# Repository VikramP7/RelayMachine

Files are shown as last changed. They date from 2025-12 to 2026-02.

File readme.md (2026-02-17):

*<div align="right"> Vikram Procter, Minh Do | Dec, 2025 </div>*

# Relay Machine - 4-bit Computer Made of Relays

## TODO
- Fix REGister LED indicator order (right most should be Q0 as its LSBs)

## Project Overview

This project implements a very simple 4-bit computer architecture 

## Systems Overview
-   ALU (computes numbers)
-   Program Memory (the program with program counter)
-   Registers (Random Access Memory)
-   Display / Routing / Clock (Displays Register Values, connections between boards)

## Components
### Relays
Using a 24V 0.15W relay [J104D2C24VDC.15S](https://www.digikey.ca/en/products/detail/cit-relay-and-switch/J104D2C24VDC-15S/12502730)

### Flyback Diodes
Using a uni-directional TVS diode [SMAJ24A](https://www.digikey.ca/en/products/detail/littelfuse-inc/SMAJ24A/762288)

### Red LED 
For important lines LED indicator [151051RS11000](https://www.digikey.ca/en/products/detail/w%C3%BCrth-elektronik/151051RS11000/4490012)

### 1.3k Resistor
Using a 1.3k resistor (2512) for current limiting LEDs [RMCF2512FT1K30](https://www.digikey.ca/en/products/detail/stackpole-electronics-inc/RMCF2512FT1K30/1758253)  

### Board to Board Connector
Board Connector 20pos 2row rectangular connector [61202021621](https://www.digikey.ca/en/products/detail/w%C3%BCrth-elektronik/61202021621/2060592)  
Cable assembly housing keyed [61202023021](https://www.digikey.ca/en/products/detail/w%C3%BCrth-elektronik/61202023021/2060600)  
Ribbon cable 20 wire 28AWG stranded [3365/20 300](https://www.digikey.ca/en/products/detail/3m/3365-20-300/1107221) or 30AWG solid [3749/20 300](https://www.digikey.ca/en/products/detail/3m/3749-20-300/22532463)

From Amazon:
General 20pos connector [here](https://www.amazon.ca/MECCANIXITY-Ribbon-2-54mm-Connector-Displays/dp/B0DQCVXGWG/ref=sr_1_1_sspa)

### Power Supply
Also avalible on amazon [here](https://www.amazon.ca/dp/B0C4YGWZQQ/ref=sspa_dk_detail_4?)

### Board Spacers 
Hex 25mm female to female M3 threaded spacer [24438](https://www.digikey.ca/en/products/detail/keystone-electronics/24438/1532170)

## Gate Implementations with Relay
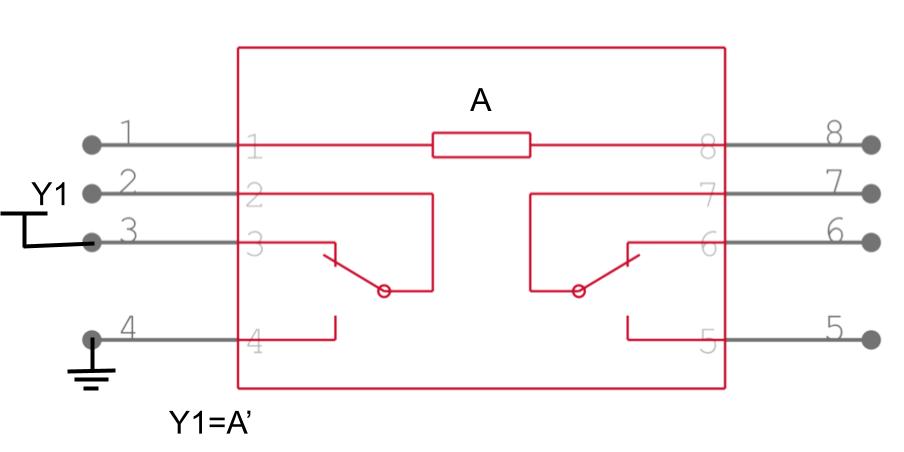
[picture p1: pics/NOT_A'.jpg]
NOT Gate

*NOT Gate Y=A'*

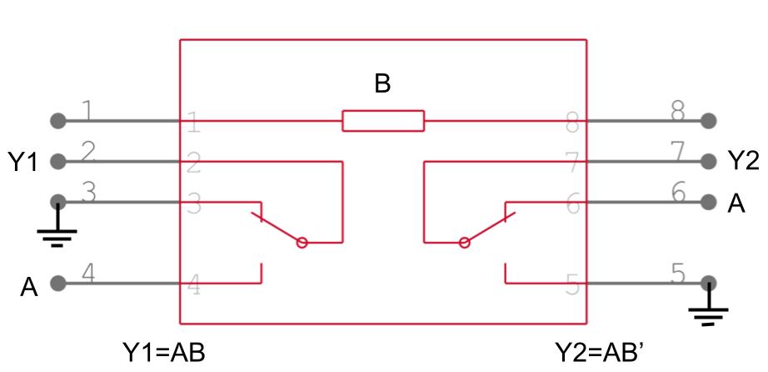
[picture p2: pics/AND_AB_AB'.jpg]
AND Gate

*AND Gate Y1=AB and Y2=AB'*

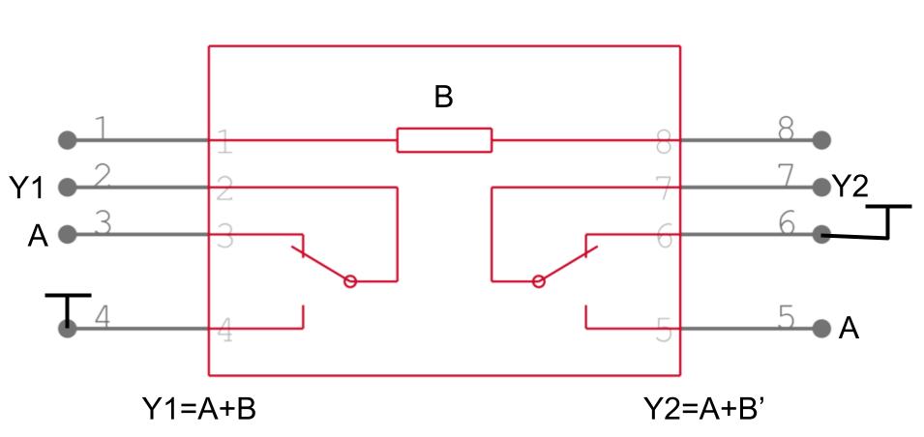
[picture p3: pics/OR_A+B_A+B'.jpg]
OR Gate

*OR Gate Y1=A+B and Y2=A+B'*

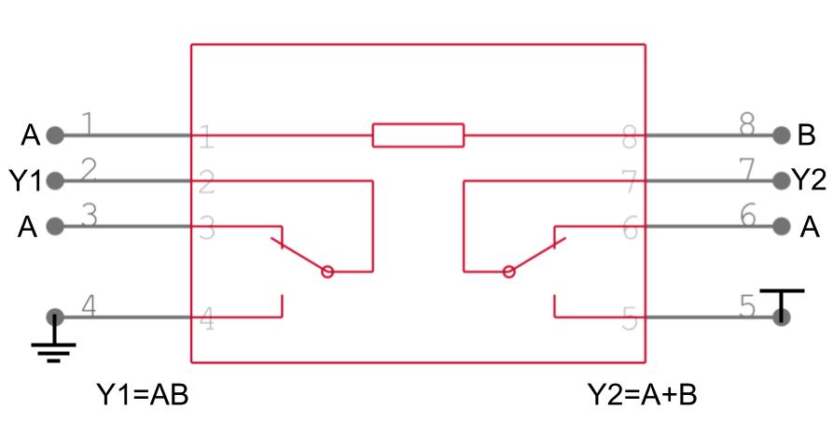
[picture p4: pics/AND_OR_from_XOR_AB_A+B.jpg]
Alternative AND OR Gate Structure

*AND or OR Gate from XOR inductor Y1=AB and Y2=A+B*

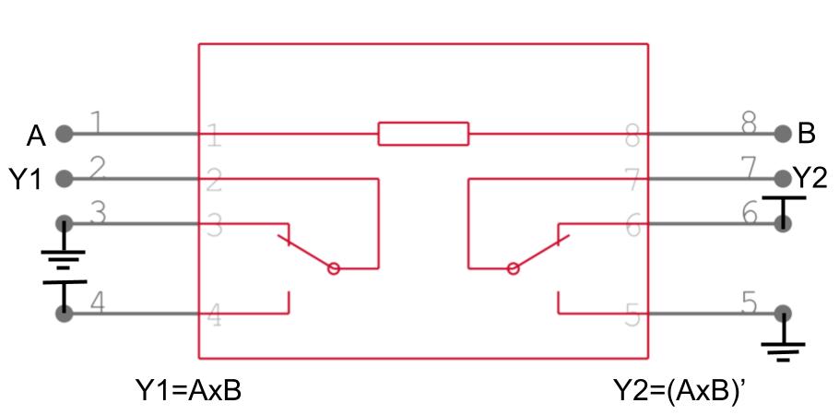
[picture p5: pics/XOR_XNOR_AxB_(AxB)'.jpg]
XOR Gate

*XOR and XNOR Gate Y1=AxB and Y2=(AxB)'*

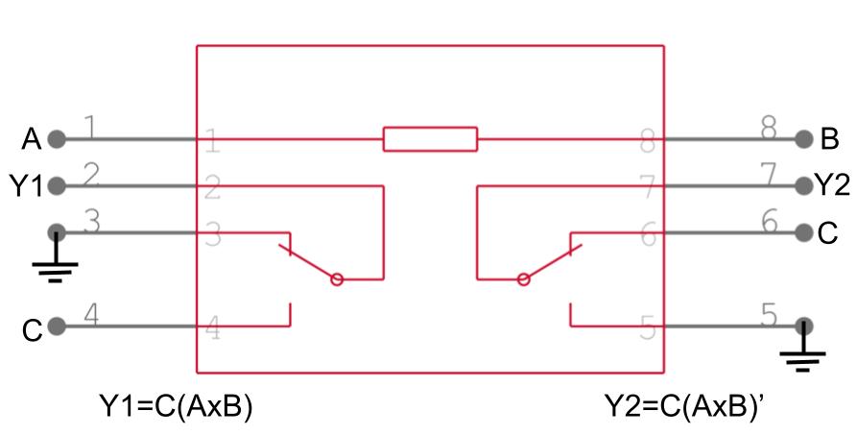
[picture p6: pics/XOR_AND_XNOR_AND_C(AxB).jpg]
XOR AND Gate

*XOR AND and XNOR AND Gate Y1=C(AxB) and Y2=C(AxB)'*

## OP-Codes
### ALU Operations:
- ADD  (addition)
- SUB  (subtraction)
- AND  (bitwise AND)
- OR   (bitwise OR)
- XOR  (bitwise exclusive OR)
- LS   (Logic shift both ways)

### Registry Operations:
- LDI  (Load immediate)
- MOV  (Move data from reg to reg)

### Program Counter Operations
- BRGE (branch if greater or equal)
- BREQ (branch if equal)
- JMP  (jump program counter)

### Miscellaneous Operations
- NOP  (No Operation)

| OpCode [3:0] | Top [3:0]  | Bottom [3:0]  | Description |
| --- | --- | --- | --- |
| 0000 | 0000 | 0000 | NOP: No Operation |
| 0001 | dddd | rrrr | ADD: Rd ← Rd + Rr |
| 0010 | dddd | rrrr | AND: Rd ← Rd & Rr |
| 0011 | dddd | rrrr | OR:  Rd ← Rd o Rr |
| 0100 | 0000 | 0000 | Not Defined
| 0101 | dddd | rrrr | SUB: Rd ← Rd - Rr |
| 0110 | dddd | rrrr | LSL: Rd ← Rd << 1 |
| 0111 | dddd | rrrr | LSR: Rd ← Rd >> 1 |
| 1000 | kkkk | kkkk | JMP: PC ← PC + k + 1 |
| 1001 | dddd | kkkk | LDI: Rd ← K
| 1010 | 0000 | 0000 | XOR: Rd ← Rd x Rr |
| 1011 | dddd | rrrr | XNOR: Rd ← Rd xn Rr
| 1100 | dddd | kkkk | BRGE: PC ← PC + k + 1 if Rd >= R1 |
| 1101 | dddd | kkkk | BREQ: PC ← PC + k + 1 if Rd == R1 |
| 1110 | dddd | kkkk | MOV: Rd ← Rr
| 1111 | 0000 | 0000 | Not Defined

## ALU Design
INPUT: 2x 4-bit buses containing the values that will be mathed

CONTROL: OP-Code control lines to select which math to be done 

OUTPUT: 2x 4-bit buses containing the outputs from the math

### Adder
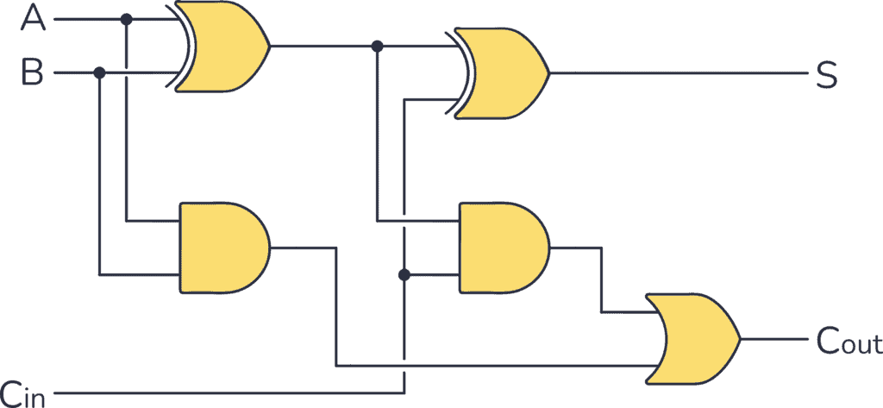
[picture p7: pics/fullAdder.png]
Full Adder

*One bit adder circuit* [Source](https://www.build-electronic-circuits.com/full-adder/)

We will utilze 4 of these modules to add the 4-bit input in a ripple carry topology

### AND/OR
Utilzize only 4 relays to do both the AND and the OR operations

### Shifters
Should not need any gates other than MUXes for outputs

Output for both Left and Right shift should be outputed on the Top and Bottom words of the output of the ALU

### MUXs
Relays themselves act as MUXes 

## Program Memory

Rough Plan is to use a bunch of dipswitches to manual program in each line of OP-Codes 

Along with a big MUX to then select which opcode line we are at based on the Program counter (PC)

## Random Access Memory (RAM)

**INPUTS:**
- 4-bit A1 (Address 1)
- 4-bit A2 (Address 2)
- 4-bit WD (Write Data)
- 1-bit WE (Write Enable)
- 1-bit CLK (Global Clock)

**OUTPUTS:**
- 4-bit RD1 (Read Data 1)
- 4-bit RD2 (Read Data 2)

### 4-Bit Register Board

**INPUTS:**
- 4-bit D (Write Data)
- 1-bit LD (Load Data Enable)
- 1-bit CLK (Global Clock)

**OUTPUTS:**
- 4-bit Q (Stored Data)

**Typically:** a NAND based solution is used, given normal people use the CMOS structure, however... NAND and NOR requires lots of relays 
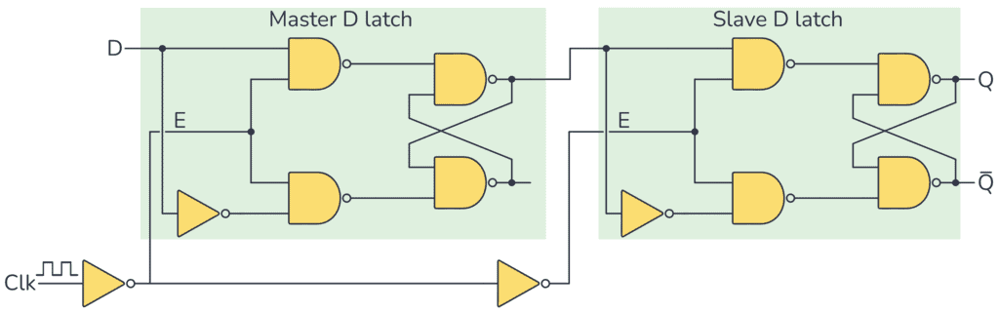
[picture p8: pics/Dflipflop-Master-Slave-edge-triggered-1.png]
D Flip Flop

*D Flip Flop NAND Based Circuit* [Source](https://www.build-electronic-circuits.com/d-flip-flop/)

or an alternative structure could be the NOR version
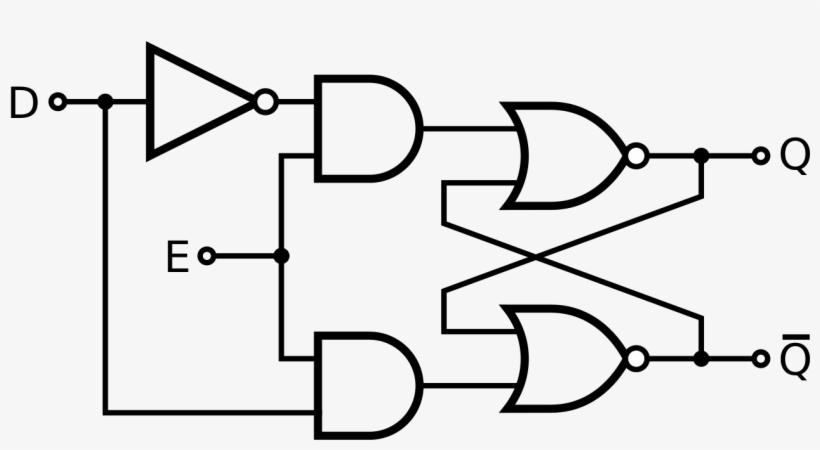
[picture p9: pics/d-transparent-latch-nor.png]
NOR Based Flip Flop

*D Latch NOR Based Circuit* [Source](https://en.wikipedia.org/wiki/Flip-flop_(electronics))

This non AND/OR based SR latch wil be used to reduce the number of relays 

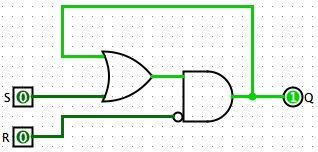
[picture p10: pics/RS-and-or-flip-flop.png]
AND-OR SR Latch


*AND-OR SR Latch Circuit* [Very Good Source](https://en.wikipedia.org/wiki/Flip-flop_(electronics))

Final D-Flip-Flop relay implementation will follow this gate structure
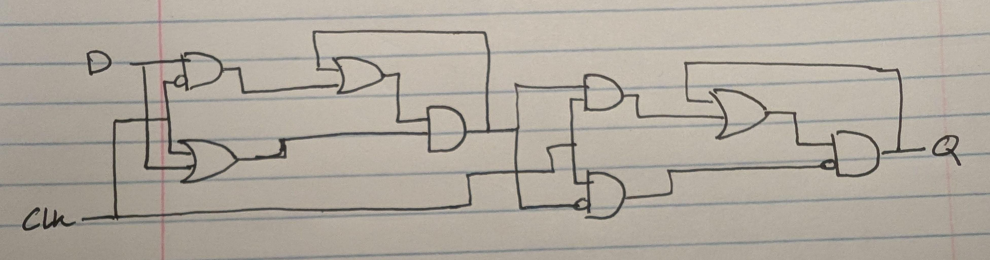
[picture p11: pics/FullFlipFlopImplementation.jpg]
Final Relay compatible implementation


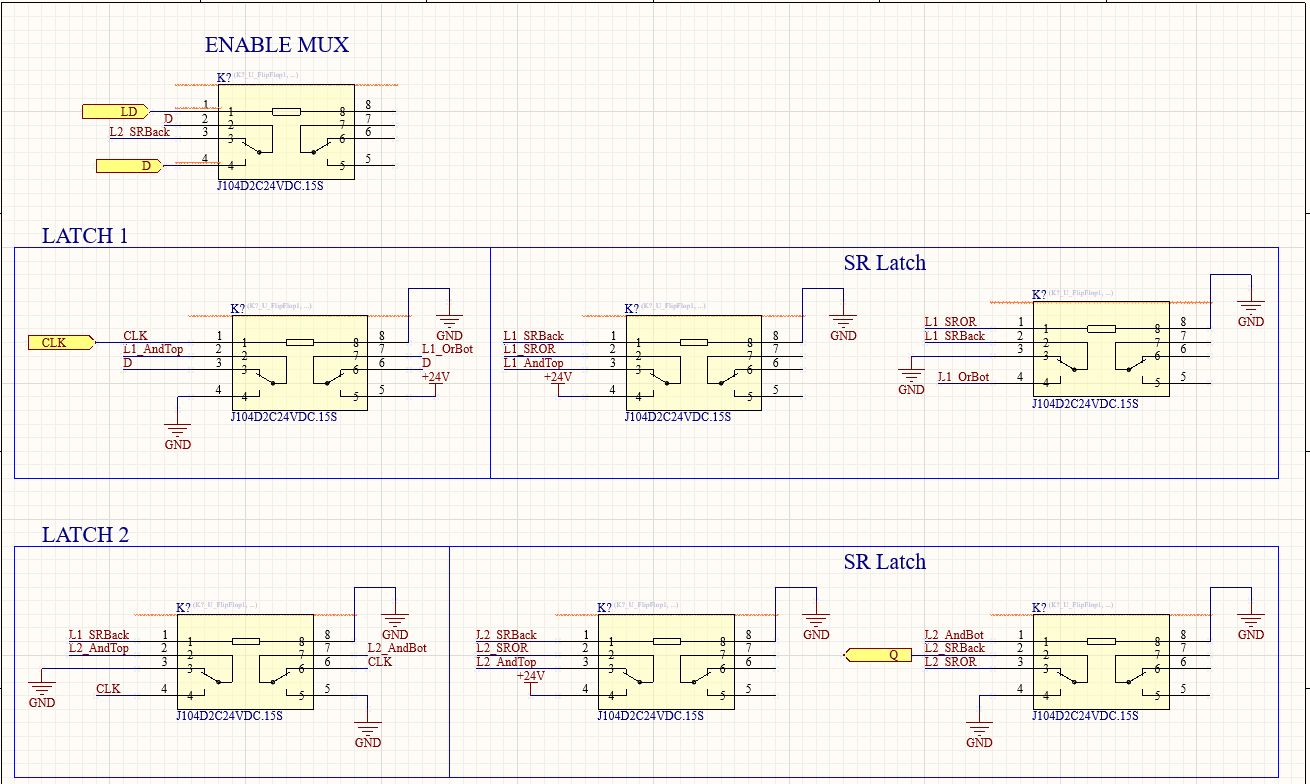
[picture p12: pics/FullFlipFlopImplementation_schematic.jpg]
Final Relay implementation for D-flip-flip


### 4 REG MUX Boards

**INPUTS:**
- 4 x 4-bit Q (Register Group's Stored Data)
- 2-bit At (Sub-Address 1 or top)
- 2-bit Ab (Sub-Address 2 or bottom)
- 4-bit WD (Write Data)
- 1-bit WE (Write Enable)
- 1-bit CLK (Global Clock)

**OUTPUTS:**
- 4 x 4-bit D (Register Group'sWrite Data)
- 1-bit LD (Load Data Enable)
- 1-bit CLK (Global Clock)
- 4-bit RDt (Read Data 1 or top)
- 4-bit RDb (Read Data 2 or bottom)

**Read Topology:**
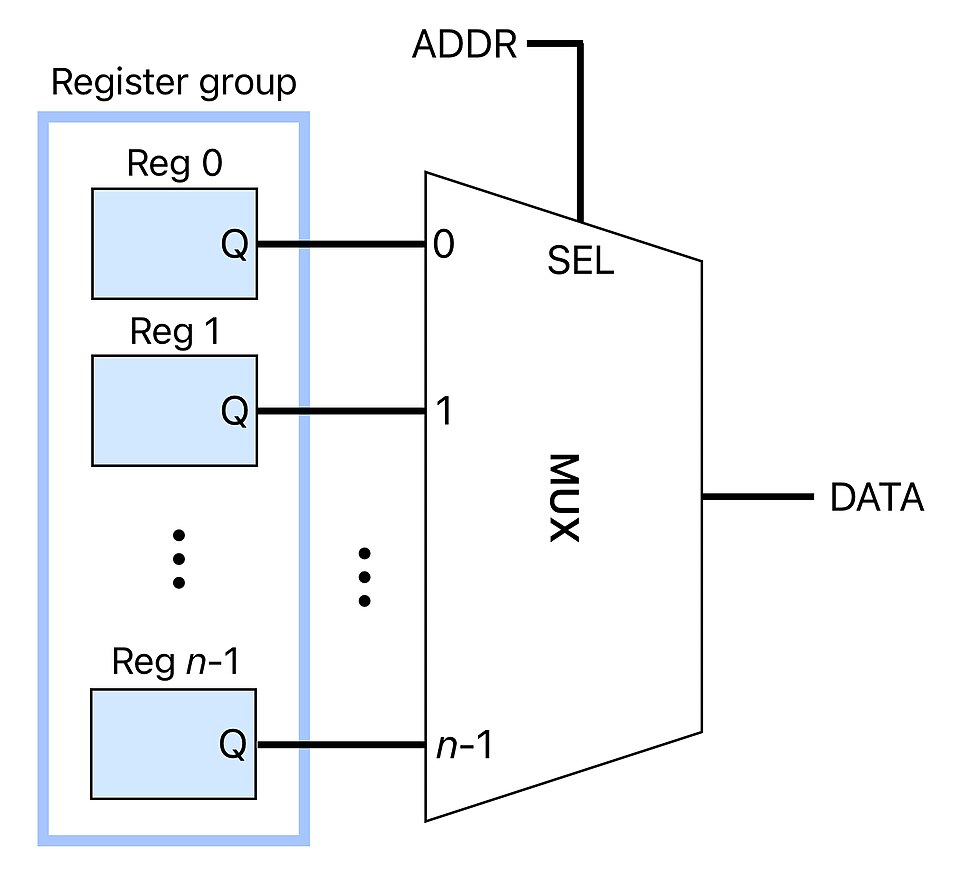
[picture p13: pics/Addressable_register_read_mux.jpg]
Addressable Read Register

*Addressable Read Register* [Source](https://en.wikipedia.org/wiki/Hardware_register)
by using cascading 4-bit MUX2s we can accomplish a full MUX8, one for each possible register. 

**Write Toplogy**
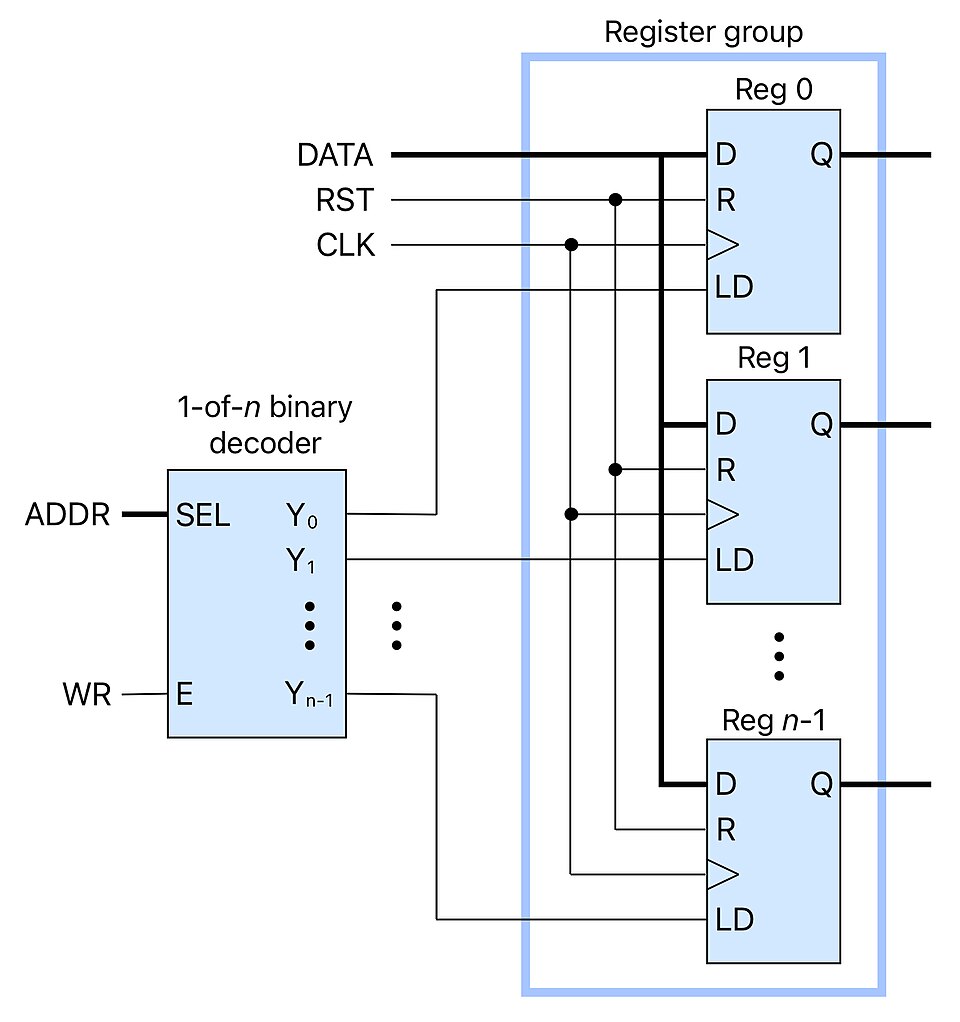
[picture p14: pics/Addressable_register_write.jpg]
Addressable Write Register

*Addressable Write Register* [Source](https://en.wikipedia.org/wiki/Hardware_register)
To create the decoder the only 3-input gate we can use is the XOR-AND gate so optimizing with that:

2&3&7, 24
5&1&7, 50
4&6, 12

$LD_0=$  
$LD_1=\overline{[A_{B0} \&\overline{(A_{B0}\oplus A_{B2})}]}\&[A_{B0} \&(A_{B0}\oplus A_{B1})]$  
$LD_2=[A_{B1} \&\overline{(A_{B2}\oplus A_{B0})}]\&[A_{B1} \&(A_{B1}\oplus A_{B2})]$  
$LD_3=\overline{[A_{B1} \&\overline{(A_{B2}\oplus A_{B0})}]}\&[A_{B1} \&(A_{B1}\oplus A_{B2})]$  
$LD_4=[A_{B2} \&\overline{(A_{B1}\oplus A_{B0})}]\&[A_{B2} \&(A_{B0}\oplus A_{B2})]$  
$LD_5=[A_{B0} \&\overline{(A_{B0}\oplus A_{B2})}]\&[A_{B0} \&(A_{B0}\oplus A_{B1})]$  
$LD_6=\overline{[A_{B2} \&\overline{(A_{B1}\oplus A_{B0})}]}\&[A_{B2} \&(A_{B0}\oplus A_{B2})]$  
$LD_7=[A_{B1} \&\overline{(A_{B2}\oplus A_{B0})}]\&\overline{[A_{B1} \& (A_{B1}\oplus A_{B2})]}$

$LD_2=[A_{B1} \&\overline{(A_{B2}\oplus A_{B0})}]\&[A_{B1} \&(A_{B1}\oplus A_{B2})]$  
$LD_3=\overline{[A_{B1} \&\overline{(A_{B2}\oplus A_{B0})}]}\&[A_{B1} \&(A_{B1}\oplus A_{B2})]$ 
$LD_7=[A_{B1} \&\overline{(A_{B2}\oplus A_{B0})}]\&\overline{[A_{B1} \& (A_{B1}\oplus A_{B2})]}$

$LD_1=\overline{[A_{B0} \&\overline{(A_{B0}\oplus A_{B2})}]}\&[A_{B0} \&(A_{B0}\oplus A_{B1})]$
$LD_5=[A_{B0} \&\overline{(A_{B0}\oplus A_{B2})}]\&[A_{B0} \&(A_{B0}\oplus A_{B1})]$  

$LD_4=[A_{B2} \&\overline{(A_{B1}\oplus A_{B0})}]\&[A_{B2} \&(A_{B0}\oplus A_{B2})]$  
$LD_6=\overline{[A_{B2} \&\overline{(A_{B1}\oplus A_{B0})}]}\&[A_{B2} \&(A_{B0}\oplus A_{B2})]$  

## Clock

Could use a RC circuit to generate a delay and use the relay itself to produce the cyclical behaviour.

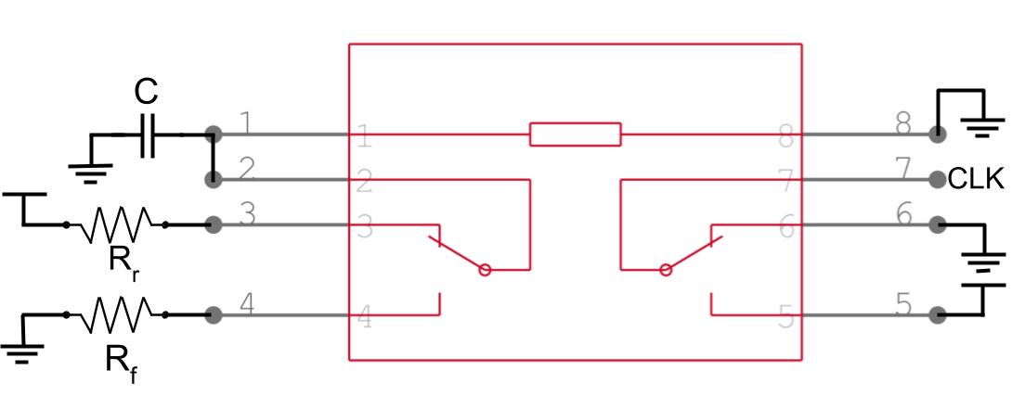
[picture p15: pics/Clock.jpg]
Image of Clock Schematic


By scaling the resistors and the capacitor various clock speeds and high/low time can be configured.

The timing should follow these equations given that clock period >> 6ms (relay actuation time)

$t_{low}=-R_r\cdot C\cdot \ln(1-\frac{V_{pickup}}{V_{DD}})$

$t_{high}=-R_f\cdot C\cdot \ln(\frac{V_{drop}}{V_{DD}})$

From the relay data sheet the $V_{pickup}=18V$ and the $V_{drop}=2.4V$

Max Capacitor current is:
$I_{max}=\frac{V_{DD}}{R}$

To keep the max current draw low like <5mA, R should be greater than 5kΩ

A 33kΩ resistor provides a current of 0.73mA keeping overall power low

Based on this resistor range a capacitance of around 4µF will be targeted. By using 8, 0.5µF caps all at 5% tolerance error should be low.  

For a 5Hz clock a period of 0.2s, using a 4µF capacitor the resistances required are:

$R_r=\frac{t_{low}}{C\cdot \ln(1-\frac{V_{pickup}}{V_{DD}})}=\frac{0.2s}{4µF\cdot \ln(1-\frac{18V}{24V})}=36.06737k\Omega$ 

$R_f=\frac{t_{high}}{C\cdot \ln(1-\frac{V_{drop}}{V_{DD}})}=\frac{0.2s}{4µF\cdot \ln(\frac{2.4V}{24V})}=21.7147k\Omega$ 

In conclusion, the resistor and capacitor values are as follows:

$C=4µF=8\cdot 0.5µF$  
$R_r=36.06737k\Omega$  
$R_f=21.7147k\Omega$

Possible 0.5µF film cap is [B32652A3504J000](https://www.digikey.ca/en/products/detail/epcos-tdk-electronics/B32652A3504J000/3491572)

## Op-Code Routing
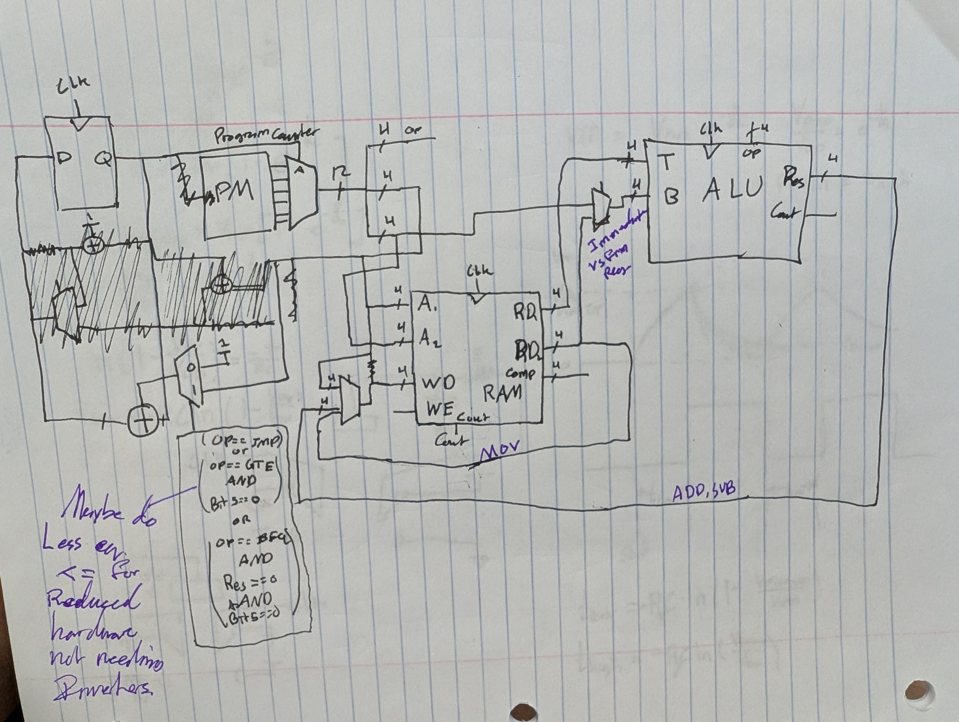
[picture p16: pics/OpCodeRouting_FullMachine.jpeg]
Draft for the full machine routing


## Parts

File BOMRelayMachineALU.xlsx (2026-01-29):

Index | Manufacturer Part Number | Manufacturer Name | Description | Attrition % | Requested Quantity 1 | Pack Quantity 1 | Pack Type 1 | Digi-Key Part Number 1 | Unit Price 1 | Extended Price 1 | Minimum Order Quantity 1 | Product Notes
1 | J104D2C24VDC.15S | CIT Relay and Switch | RELAY GEN PURPOSE DPDT 2A 24V |  | 100 | 100 | Tube | 2449-J104D2C24VDC.15S-ND | 1.44330 | $144.33 | 1
2 | SMAJ24A | Littelfuse Inc. | TVS DIODE 24VWM 38.9VC DO214AC |  | 100 | 100 | Cut Tape (CT) | SMAJ24ALFCT-ND | 0.10700 | $10.70 | 1
3 | 151051RS11000 | Würth Elektronik | LED RED DIFFUSED 5MM ROUND T/H |  | 100 | 100 | Bulk | 732-5016-ND | 0.18450 | $18.45 | 1
4 | RMCF2512FT1K30 | Stackpole Electronics Inc | RES 1.3K OHM 1% 1W 2512 |  | 100 | 100 | Cut Tape (CT) | RMCF2512FT1K30CT-ND | 0.11580 | $11.58 | 1
5 | 61202021621 | Würth Elektronik | CONN HEADER VERT 20POS 2.54MM |  | 5 | 5 | Tray | 732-2096-ND | 1.24000 | $6.20 | 1
6 | 61202023021 | Würth Elektronik | CONN RCPT 20POS IDC 28AWG GOLD |  | 5 | 5 | Tray | 732-2104-ND | 1.54000 | $7.70 | 1
7 | 3365/20 300 | 3M | CBL RIBN 20COND 0.05 GRAY 300' |  | 25 | 25 | DIGI_SPOOL | 19-3365/20300-DS-ND | 1.08680 | $27.17 | 1

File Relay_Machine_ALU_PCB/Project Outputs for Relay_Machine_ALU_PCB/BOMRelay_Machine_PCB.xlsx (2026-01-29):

Line # | Name | Description | Designator | Quantity | Manufacturer 1 | Manufacturer Part Number 1 | Manufacturer Lifecycle 1 | Supplier 1 | Supplier Part Number 1 | Supplier Unit Price 1 | Supplier Subtotal 1
 | SMAJ24A | SMAJ Series 400 W 24 V Uni-Directional Surface Mount TVS Diode - DO-214AC | D1, D2, D3, D4, D5, D6, D7, D8, D9, D10, D11, D12, D13, D14, D15, D16, D17, D18, D19, D20, D21, D22, D23, D24, D25, D26, D27, D28, D29, D30, D31, D32, D33, D34, D35, D36, D37, D38, D39, D40, D41, D42, D43, D44, D45, D46, D47, D48, D49, D50, D51, D52 | 54
 | RED | WL-TMRC Red Color Diffused 5 mm Round Through Hole LED | DS1, DS2, DS3, DS4, DS5, DS6, DS7, DS8, DS9, DS10, DS11, DS12, DS13, DS14, DS15, DS16, DS17, DS18, DS19, DS20, DS21, DS22, DS23, DS24, DS25, DS26, DS27, DS28, DS29, DS30, DS31, DS32, DS33, DS34, DS35, DS36, DS37, DS38, DS39, DS40, DS41, DS42 | 42
 | Con 61202021621 | WR-BHD Straight Male, Box Header, Through Hole, 2 Rows, 20 Contacts, 2.54mm Pitch | J1, J2 | 2
 | J104D2C24VDC.15S | Relay Ul Gen Purp DPDT 2C 24VDC | K1, K2, K3, K4, K5, K6, K7, K8, K9, K10, K11, K12, K13, K14, K15, K16, K17, K18, K19, K20, K21, K22, K23, K24, K25, K26, K27, K28, K29, K30, K31, K32, K33, K34, K35, K36, K37, K38, K39, K40 | 41
 | 1.3k | Res Thick Film 2512 1.3K Ohm 1% 1W ±100ppm/C Pad SMD Automotive T/R RMCF2512FT1K30 | R1, R2, R3, R4, R?1, R?2, R?3, R?4, R?5, R?6, R?7, R?8, R?9, R?10, R?11, R?12, R?13, R?14, R?15, R?16, R?17, R?18, R?19, R?20, R?21, R?22, R?23, R?24, R?25, R?26, R?27, R?28, R?29, R?30, R?31, R?32, R?33, R?34, R?35, R?36, R?37, R?38 | 42

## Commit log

2025-12-11 Added Gate Relay implementations
2025-12-11 Added relay gate images to MD
2025-12-11 Created Altium PCB Project
    [PcbLib1.PcbLib, Relay_Machine_PCB.PrjPcb, Schlib1.SchLib]
2025-12-11 Added A bunch of stuff to the PCB
    [ALU.SchDoc, ANDOR4.SchDoc, Mux2.SchDoc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]
2025-12-11 This won't work
    [Relay_Machine_PCB.PrjPcb]
2025-12-11 Last time
    [Relay_Machine_PCB.PrjPcb]
2025-12-12 Added reusable device sheets for full bit adder and the 4bit mux
    [4bitMux2.SchDoc, FullAdder.SchDoc, Mux2.SchDoc]
2025-12-12 Added some implementation of adder and mux to ALU toplevel
    [ALU.SchDoc, Mux2.SchDoc, Relay_Machine_PCB.PrjPcb]
2025-12-15 Finished the ALU Schematic
    [1bitMux2.SchDoc, ALU.SchDoc, ANDOR4.SchDoc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]
2025-12-16 Added PCB and tried to annotate
    [1bitMux2.SchDoc, ALU.SchDoc, ANDOR4.SchDoc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]
2025-12-20 Fixed Annotation problems and added connectors
    [1bitMux2.SchDoc, 4bitMux2.SchDoc, ALU.SchDoc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]
2025-12-20 updated components list to contain the spacers and connectors
2025-12-20 Added More indicator LEDs and did more routing
    [ALU.SchDoc]
2025-12-22 Routed some more
    [4bitMux2.SchDoc, ALU.SchDoc, PCB_ALU.PcbDoc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]
2026-01-02 Started Routing
    [ALU.SchDoc, PCB_ALU.PcbDoc, Relay_Machine_PCB.PrjPcb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]
2026-01-03 Lots more Routing Occured
    [ANDOR4.SchDoc, PCB_ALU.PcbDoc, XORXNOR1.SchDoc]
2026-01-03 Finished routing now just adding goofy stuff
    [ALU.SchDoc, PCB_ALU.PcbDoc]
2026-01-27 Added Stitching vias
    [Relay_Machine_PCB.PrjPcb]
2026-01-29 Small silk screen and added ground pours with stitching
    [Relay_Machine_ALU_PCB.PrjPcb]
2026-01-29 Created ALU BOM
    [BOMRelayMachineALU.xlsx]
2026-01-29 ALU ground pours and created RAM Board project
    [ALU.SchDoc, ANDOR4.SchDoc, BOMRelay_Machine_PCB.xlsx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]
2026-01-29 Created the Flip flop schematic i think there is one saved in the wrong spot
    [FlipFlop.SchDoc, SR_Latch.SchDoc]
2026-01-29 Added Mounting Holes for smaler boards
    [ALU.SchDoc]
2026-01-30 Finished routing the single register board
    [FlipFlop.SchDoc, PCB_REG.PcbDoc, RAM_top.SchDoc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]
2026-01-30 Renamed project from ram to reg
    [FlipFlop.SchDoc, PCB_REG.PcbDoc, REG_top.SchDoc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]
2026-01-30 Created the RAM module project and started schematic
    [RAM_top.SchDoc, Relay_Machine_RAM_PCB.PrjPcb]
2026-01-30 Added LED inicators to the REG board
    [PCB_REG.PcbDoc, REG_top.SchDoc]
2026-02-03 Added labels for each of the register groups
    [PCB_REG.PcbDoc]
2026-02-04 Added libraries to RAM, added pcb template, and added a bunch of connectors to the board
    [PCB_RAM.PcbDoc, PCB_REG.PcbDoc, RAM_top.SchDoc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]
2026-02-05 The current board design will not work :(
    [4bitMux2_flipped.SchDoc, PCB_RAM1.PcbDoc, RAM1_top.SchDoc]
2026-02-05 Ram still doesn't work. Also added the powersupply and board connector links amazon links to readme
    [PCB_RAM1.PcbDoc, RAM1_top.SchDoc, Relay_Machine_RAM1_PCB.PrjPcb]
2026-02-12 Working on ram stuffs
    [4bitDecoder.SchDoc, PCB_RAM_MUX4.PcbDoc, RAM_MUX4_top.SchDoc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]
2026-02-17 Specified RAM Board stuffs
2026-02-17 RAM schematic should be done, moving to PCB layout
    [4bitDecoder.SchDoc, PCB_RAM_MUX4.PcbDoc, PCB_REG.PcbDoc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]
2026-02-20 Added silk screen to label the connector pins
    [PCB_REG.PcbDoc]
2026-02-20 Routed the 4MUX for registers part of RAM
    [PCB_RAM_MUX4.PcbDoc, RAM_MUX4_top.SchDoc]
2026-02-21 More RAM MUX4 routing
    [4bitDecoder.SchDoc, PCB_RAM_MUX4.PcbDoc, RAM_MUX4_top.SchDoc]
